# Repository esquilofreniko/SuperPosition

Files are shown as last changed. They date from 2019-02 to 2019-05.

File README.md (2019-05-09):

**SuperPosition – Rev 1**

**Bill of Materials:**

|Function / Name 		|# |Note 								|Part Number 		|
|---|--|---|---|
|MCU Teensy 3.5/3.6 	|1 |Cut USB power trace 				|DEV-14057 			|
|Display OLED SSD1306 	|1 |SSD1306 / SPI / 0.96’’ / 128x64 [1] | 					|
|Adafruit NeoTrellis 	|1 |4x4 RGB LED Button Matrix [2] 		|Mouser: 485-1616 	|
|Silicone 4x4 Keypad 	|1 |Silicone Elastomer Button Keypad [3]|Mouser: 485-1611 	|
|Rotary Encoder 		|2 |24 Pulse Mechanical Rotary Encoder 	|PEC11R-4220F -S0024|
|Tactile Switch 		|2 |9.4mm Black Button Tactile Switch 	|2-1825910-7 		|
|3.5mm Jacks 			|12 |“Thonkiconn” Mono Jacks from Thonk |PJ398SM 			|
|DAC MCP4922 			|2 |12-bit Digital to Analog Converter 	|MCP4922-E/P 		|
|Op-amp MCP6004 		|1 |Operational Amplifier 				|MCP6004-E/P 		|
|Op-amp TL04CN 			|2 |Operational Amplifier 				|TL074CN 			|
|Regulator L7805 		|1 |5V Voltage Regulator 				|L7805CP 			|
|Diode 1N5817 			|2 |Through Hole 						|1N5817 			|
|Resistor 100k SMD 0805 |24|0.1% 								| 					|
|Resistor 56k SMD 0805 	|4 |0.1% 								| 					|
|Resistor 1k SMD 0805 	|8 |1% 									| 					|
|Capacitor 10u SMD 0805 |2 |Ceramic Capacitor 					| 					|
|Capacitor 100n SMD 0805|6 |Ceramic Capacitor 					|					|

[1] https://www.amazon.co.uk/IZOKEE-Display-SSD1306-Raspberry-White-IIC/dp/B076PKKTRP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

[2] https://www.adafruit.com/product/3954

[3] https://www.adafruit.com/product/1611

**Build Guide (work in progress):**  

1. Solder the 2 10u 0805 SMT Capacitors in the front;

2. Solder the 6 100n 0805 SMT Capacitors in the back;

3. Solder all the 0805 SMT Resistors in the back;

4. Solder the 1N5817 Diodes in the back;

5. Solder the L7805 Voltage Regulator in the back;

6. Solder the Power Header in the back;

7. Solder the pin sockets for the teensy in the back;

8. Solder the ICs in the front (MCP6004, TL074CN, MCP4922);

9. Solder the buttons and encoders in the front;

10. Solder all of the jacks on the top;

11. Solder the Adafruit NeoTrellis PCB in the front;

12. Solder the OLED Display in the front;

13. Place the Panel on the front of the PCB;

14. Cut the USB power trace on the back of the teensy;

15. Place the teensy on the back;

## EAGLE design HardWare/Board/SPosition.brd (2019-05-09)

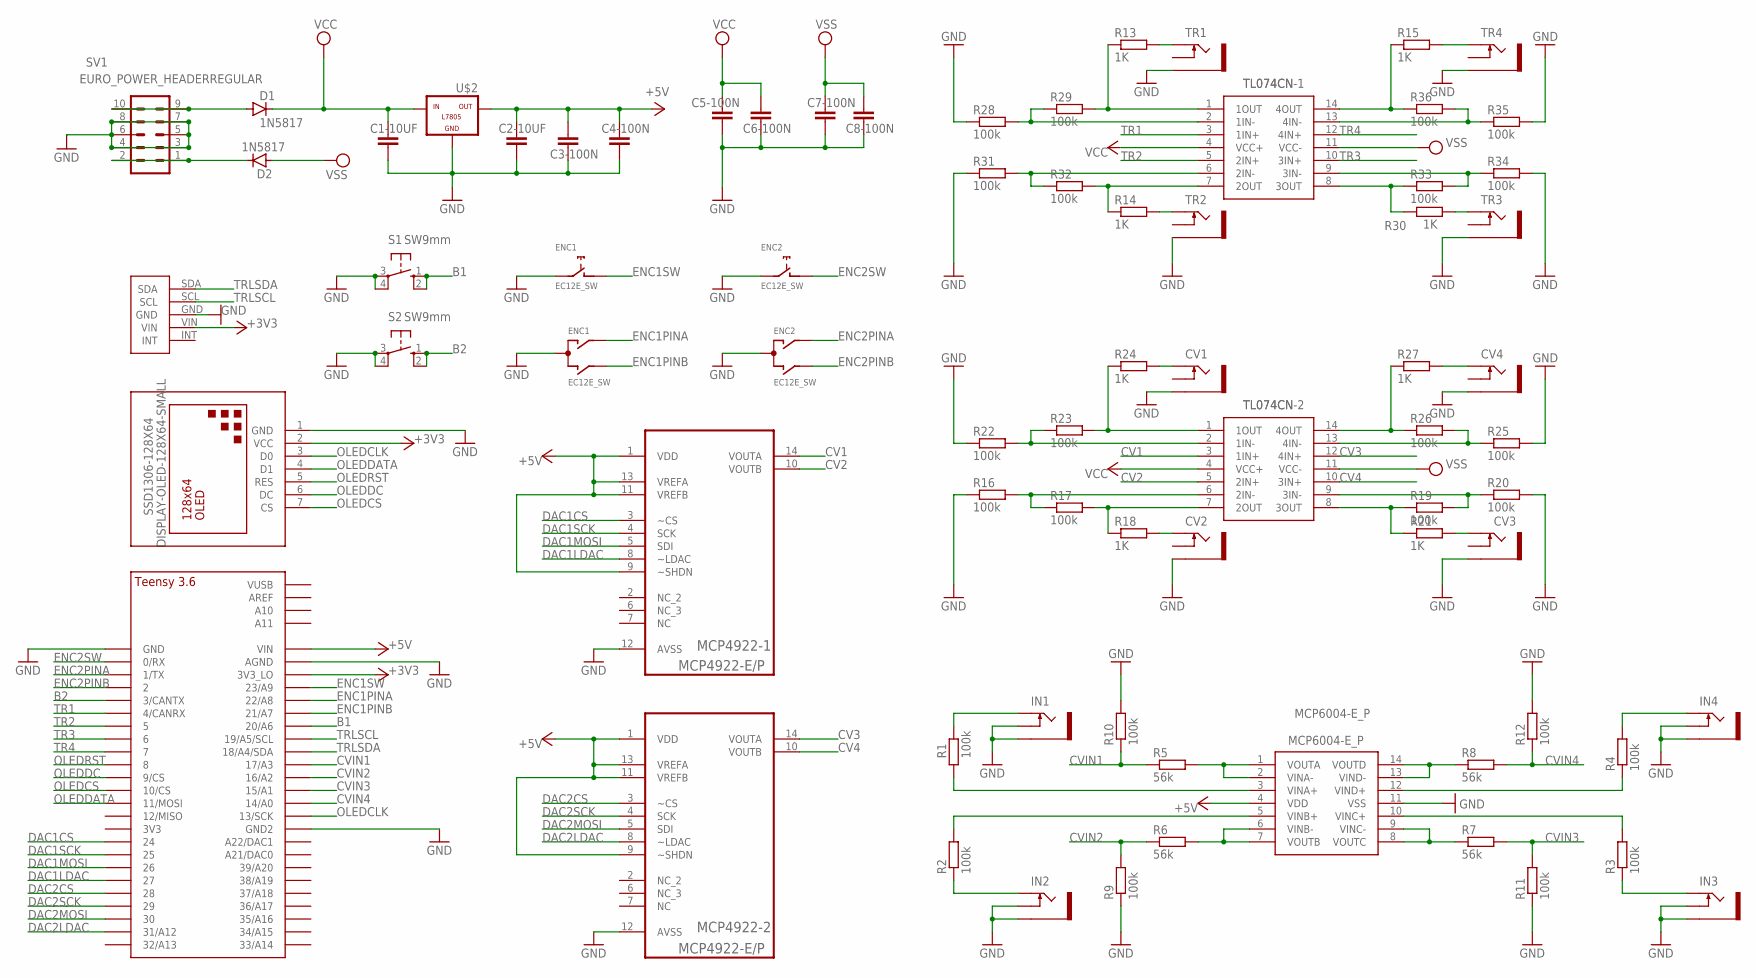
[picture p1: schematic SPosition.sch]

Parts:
C1-10UF, C2-10UF: 10uF; C0805
C3-100N, C4-100N, C5-100N, C6-100N, C7-100N, C8-100N: 100n; C0805
CV1, CV2, CV3, CV4: THONKICONNNEW; WQP-PJ301M-12_JACK
D1, D2: 1N5817; DO41-10
ENC1, ENC2: EC12E_SW; ALPS_EC12E_SW
IN1, IN2, IN3, IN4: THONKICONNNEW; WQP-PJ301M-12_JACK
MCP4922-1, MCP4922-2: MCP4922-E/P; DIP254P762X533-14
MCP6004-E_P: MCP6004-E_P; DIP781W56P254L1918H533Q14N
R1, R2, R3, R4, R9, R10, R11, R12, R16, R17, R19, R20, R22, R23, R25, R26, R28, R29, R31, R32, R33, R34, R35, R36: 100k; R0805
R5, R6, R7, R8: 56k; R0805
R13, R14, R15, R18, R21, R24, R27, R30: 1K; R0805
S1, S2: SW9mm; B3F-10XX
SSD1306-128X64: DISPLAY-OLED-128X64-SMALL
SV1: EURO_POWER_HEADERREGULAR; EURO_POWER_HEADER
TL074CN-1, TL074CN-2: TL074CN; DIP794W53P254L1930H508Q14N
TR1, TR2, TR3, TR4: THONKICONNNEW; WQP-PJ301M-12_JACK
U$1: TEENSY_3.5/3.6_BASIC
U$2: -L7805; L7805
U$4: SPREV5

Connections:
+3V3: SSD1306-128X64.2 (VCC), U$1.3V3_LO, U$4.VIN
+5V: C2-10UF.1, C3-100N.1, C4-100N.1, MCP4922-1.1 (VDD), MCP4922-1.9 (~SHDN), MCP4922-1.11 (VREFB), MCP4922-1.13 (VREFA), MCP4922-2.1 (VDD), MCP4922-2.9 (~SHDN), MCP4922-2.11 (VREFB), MCP4922-2.13 (VREFA), MCP6004-E_P.4 (VDD), U$1.VIN, U$2.OUT
B1: S1.1 (S), S1.2 (S1), U$1.20/A6
B2: S2.1 (S), S2.2 (S1), U$1.3/CANTX
CV1: MCP4922-1.14 (VOUTA), TL074CN-2.3 (1IN+)
CV2: MCP4922-1.10 (VOUTB), TL074CN-2.5 (2IN+)
CV3: MCP4922-2.14 (VOUTA), TL074CN-2.12 (4IN+)
CV4: MCP4922-2.10 (VOUTB), TL074CN-2.10 (3IN+)
CVIN1: R5.1, R10.1, U$1.17/A3
CVIN2: R6.1, R9.2, U$1.16/A2
CVIN3: R7.2, R11.2, U$1.15/A1
CVIN4: R8.2, R12.1, U$1.14/A0
DAC1CS: MCP4922-1.3 (~CS), U$1.24
DAC1LDAC: MCP4922-1.8 (~LDAC), U$1.27
DAC1MOSI: MCP4922-1.5 (SDI), U$1.26
DAC1SCK: MCP4922-1.4 (SCK), U$1.25
DAC2CS: MCP4922-2.3 (~CS), U$1.28
DAC2LDAC: MCP4922-2.8 (~LDAC), U$1.31/A12
DAC2MOSI: MCP4922-2.5 (SDI), U$1.30
DAC2SCK: MCP4922-2.4 (SCK), U$1.29
ENC1PINA: ENC1.A, U$1.22/A8
ENC1PINB: ENC1.B, U$1.21/A7
ENC1SW: ENC1.D (1), U$1.23/A9
ENC2PINA: ENC2.A, U$1.1/TX
ENC2PINB: ENC2.B, U$1.2
ENC2SW: ENC2.D (1), U$1.0/RX
GND: C1-10UF.2, C2-10UF.2, C3-100N.2, C4-100N.2, C5-100N.2, C6-100N.2, C7-100N.2, C8-100N.2, CV1.P$3_SLEEVE (SLEEVE), CV2.P$3_SLEEVE (SLEEVE), CV3.P$3_SLEEVE (SLEEVE), CV4.P$3_SLEEVE (SLEEVE), ENC1.C, ENC1.E (2), ENC2.C, ENC2.E (2), IN1.P$2_SWITCH (SWITCH), IN1.P$3_SLEEVE (SLEEVE), IN2.P$2_SWITCH (SWITCH), IN2.P$3_SLEEVE (SLEEVE), IN3.P$2_SWITCH (SWITCH), IN3.P$3_SLEEVE (SLEEVE), IN4.P$2_SWITCH (SWITCH), IN4.P$3_SLEEVE (SLEEVE), MCP4922-1.12 (AVSS), MCP4922-2.12 (AVSS), MCP6004-E_P.11 (VSS), R9.1, R10.2, R11.1, R12.2, R16.1, R20.2, R22.1, R25.2, R28.1, R31.1, R34.2, R35.2, S1.3, S1.4 (P1), S2.3, S2.4 (P1), SSD1306-128X64.1 (GND), SV1.3, SV1.4, SV1.5, SV1.6, SV1.7, SV1.8, TR1.P$3_SLEEVE (SLEEVE), TR2.P$3_SLEEVE (SLEEVE), TR3.P$3_SLEEVE (SLEEVE), TR4.P$3_SLEEVE (SLEEVE), U$1.AGND, U$1.GND, U$1.GND2, U$2.GND, U$4.GND
unnamed: D1.A, SV1.9, SV1.10
unnamed: R17.2, R18.1, TL074CN-2.7 (2OUT)
unnamed: IN1.P$1_TIP (TIP), R1.2
unnamed: MCP6004-E_P.6 (VINB-), MCP6004-E_P.7 (VOUTB), R6.2
unnamed: IN2.P$1_TIP (TIP), R2.1
unnamed: IN3.P$1_TIP (TIP), R3.1
unnamed: R14.1, R32.2, TL074CN-1.7 (2OUT)
unnamed: IN4.P$1_TIP (TIP), R4.2
unnamed: MCP6004-E_P.5 (VINB+), R2.2
unnamed: MCP6004-E_P.13 (VIND-), MCP6004-E_P.14 (VOUTD), R8.1
unnamed: MCP6004-E_P.8 (VOUTC), MCP6004-E_P.9 (VINC-), R7.1
unnamed: MCP6004-E_P.3 (VINA+), R1.1
unnamed: MCP6004-E_P.10 (VINC+), R3.2
unnamed: MCP6004-E_P.12 (VIND+), R4.1
unnamed: R16.2, R17.1, TL074CN-2.6 (2IN-)
unnamed: MCP6004-E_P.1 (VOUTA), MCP6004-E_P.2 (VINA-), R5.2
unnamed: CV2.P$1_TIP (TIP), R18.2
unnamed: CV3.P$1_TIP (TIP), R21.2
unnamed: R19.1, R21.1, TL074CN-2.8 (3OUT)
unnamed: R19.2, R20.1, TL074CN-2.9 (3IN-)
unnamed: R22.2, R23.1, TL074CN-2.2 (1IN-)
unnamed: R23.2, R24.1, TL074CN-2.1 (1OUT)
unnamed: CV1.P$1_TIP (TIP), R24.2
unnamed: R25.1, R26.2, TL074CN-2.13 (4IN-)
unnamed: R26.1, R27.1, TL074CN-2.14 (4OUT)
unnamed: CV4.P$1_TIP (TIP), R27.2
unnamed: D2.C, SV1.1, SV1.2
unnamed: R28.2, R29.1, TL074CN-1.2 (1IN-)
unnamed: R13.1, R29.2, TL074CN-1.1 (1OUT)
unnamed: R31.2, R32.1, TL074CN-1.6 (2IN-)
unnamed: R13.2, TR1.P$1_TIP (TIP)
unnamed: R14.2, TR2.P$1_TIP (TIP)
unnamed: R33.2, R34.1, TL074CN-1.9 (3IN-)
unnamed: R30.2, TR3.P$1_TIP (TIP)
unnamed: R30.1, R33.1, TL074CN-1.8 (3OUT)
unnamed: R35.1, R36.2, TL074CN-1.13 (4IN-)
unnamed: R15.1, R36.1, TL074CN-1.14 (4OUT)
unnamed: R15.2, TR4.P$1_TIP (TIP)
OLEDCLK: SSD1306-128X64.3 (D0), U$1.13/SCK
OLEDCS: SSD1306-128X64.7 (CS), U$1.10/CS
OLEDDATA: SSD1306-128X64.4 (D1), U$1.11/MOSI
OLEDDC: SSD1306-128X64.6 (DC), U$1.9/CS
OLEDRST: SSD1306-128X64.5 (RES), U$1.8
TR1: TL074CN-1.3 (1IN+), U$1.4/CANRX
TR2: TL074CN-1.5 (2IN+), U$1.5
TR3: TL074CN-1.10 (3IN+), U$1.6
TR4: TL074CN-1.12 (4IN+), U$1.7
TRLSCL: U$1.19/A5/SCL, U$4.SCL
TRLSDA: U$1.18/A4/SDA, U$4.SDA
VCC: C1-10UF.1, C5-100N.1, C6-100N.1, D1.C, TL074CN-1.4 (VCC+), TL074CN-2.4 (VCC+), U$2.IN
VSS: C7-100N.1, C8-100N.1, D2.A, TL074CN-1.11 (VCC-), TL074CN-2.11 (VCC-)

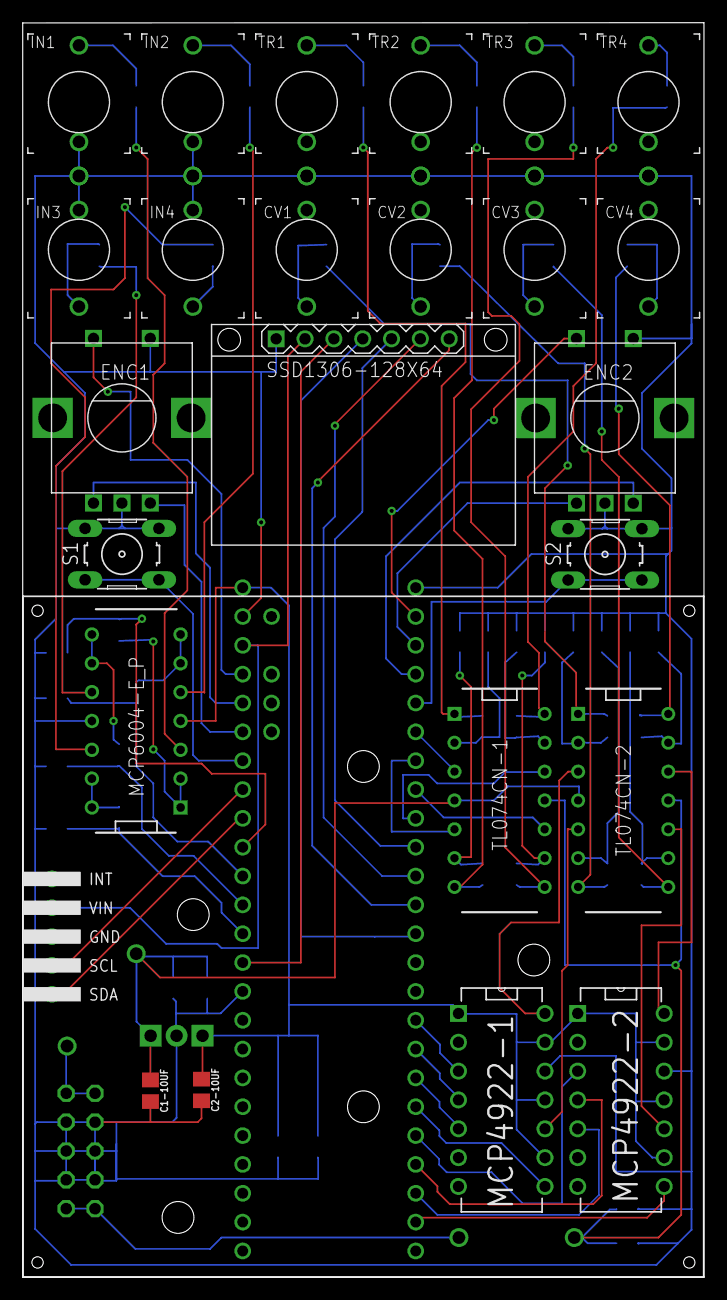
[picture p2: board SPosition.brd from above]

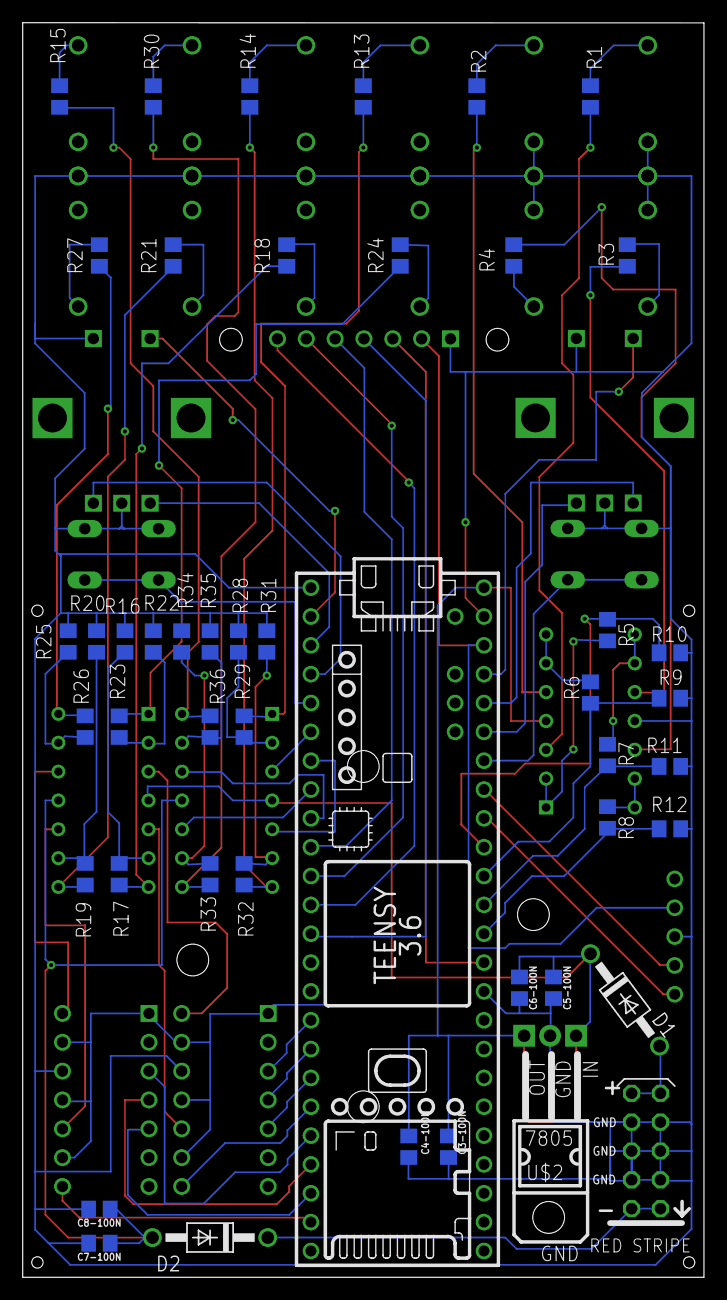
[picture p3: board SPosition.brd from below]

Board: 2 copper layers, 60.0 x 110.5 mm, 72 parts (47 on the bottom side), 78 nets.

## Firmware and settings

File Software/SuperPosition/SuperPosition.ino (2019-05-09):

#include "SP_hardware.h"
#include "SP_MODE.h"
int mode = 2;
int oldmode = mode;

void setup(){
  // loadPreset();
  hardware_init();
}

void loop(){
  hardware_read();
  if(mode == 0){mainMenu.run();}
  if(mode == 1){calibration.run();}
  if(mode == 2){gen.run();}
  if(oled.redraw == 1){oled.show();oled.redraw = 0;}
  if(millis() - oled.lastRedrawMS > 50){
    oled.clear();
    oled.redraw = 1;
    oled.lastRedrawMS = millis();
    // kp.show();
  }
  if(oldmode != mode){oled.clear();oled.redraw=1;oldmode=mode;}
}

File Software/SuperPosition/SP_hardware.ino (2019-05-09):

//Inputs
ADC::ADC(byte _pin1,byte _pin2,byte _pin3,byte _pin4):
  pin1(_pin1),
  pin2(_pin2),
  pin3(_pin3),
  pin4(_pin4)
{};

void ADC::init(){
  pin[0] = pin1;
  pin[1] = pin2;
  pin[2] = pin3;
  pin[3] = pin4;
  for(int i=0;i<4;i++){
    gate[4] = 0;
    _gate[4] = 0;
    pinMode(pin[i],INPUT);
  }
};

void ADC::read(){
  for(int i=3;i>-1;i--){
    trig[i] = 0;
    avg[i][avgCounter] = analogRead(pin[i]);
    gate[i] = digitalRead(pin[i]);
    if(gate[i] == 1 && _gate[i]==0){trig[i] = 1;}
    _gate[i] = gate[i];
  }
  avgCounter++;
  avgCounter %= avgMax;
  if(avgCounter == 0){    
    for(int i=3;i>-1;i--){
      in[i] = 0;
      for(int j=0;j<avgMax;j++){
        in[i] += avg[i][j];
      }
      in[i] = in[i] / avgMax;
    }
  }
};

//Digital Outputs
Gate::Gate(byte _pin1,byte _pin2,byte _pin3,byte _pin4):
  pin1(_pin1),
  pin2(_pin2),
  pin3(_pin3),
  pin4(_pin4)
{};

void Gate::init(){
  pin[0] = pin1;
  pin[1] = pin2;
  pin[2] = pin3;
  pin[3] = pin4;
  for(int i=0;i<4;i++){
    pinMode(pin[i],OUTPUT);
    digitalWrite(pin[i],0);
  };
}

void Gate::read(){
  for(int i=0;i<4;i++){
    if(trigger[i] == 1){
      if(val[i] == 1 && prev[i] == 0){
        trigStart = millis();
      }
      else if (val[i] == 1 && prev[i] == 1){
        if(millis() - trigStart > trigTime){
          digitalWrite(pin[i],0);
          val[i] = 0;
        }
      }
      prev[i] = val[i];
    }
  }
}

void Gate::write(byte channel, bool _val){
  digitalWrite(pin[channel],_val);
  val[channel] = _val;
}

//Analog Outputs
DAC::DAC(SP_MCP4922 _a1,SP_MCP4922 _a2,SP_MCP4922 _a3,SP_MCP4922 _a4):
a1(_a1),
a2(_a2),
a3(_a3),
a4(_a4)
{};

void DAC::init(){
  a1.setValue(0);
  a2.setValue(0);
  a3.setValue(0);
  a4.setValue(0);
};

void DAC::write(byte channel, float voltage){
  voltage = voltage * 0.99; //1k Output Resistor
  // if(voltage != 0){
  //   if(channel == 0){
  //     voltage += 0.012;
  //   }
  //   else if(channel == 1){
  //     voltage += 0.015;
  //   }
  //   else if(channel == 2){
  //     voltage += 0;
  //   }
  //   else if(channel == 3){
  //     voltage += 0.009;
  //   }
  // }
  int output = map(voltage,0,10,0,4095);
  if(channel == 0){
    a1.setValue(output);
  }
  else if(channel == 1){
    a2.setValue(output);
  }
  else if(channel == 2){
    a3.setValue(output);
  }
  else if(channel == 3){
    a4.setValue(output);
  }
};

//Buttons
Button::Button(byte _pin):
  pin(_pin)
{};

void Button::init() {
  pinMode(pin, INPUT_PULLUP);
  state = 1;
};

void Button::read() {
  clicked = 0;
  held_t = 0;
  bool prevHeld = held;
  int prevState = state;
  state = digitalRead(pin);
  if (prevState == 1 && state == 0){buttonDownMs = millis();}
  if (prevState == 0 && state == 1) {
    if (millis() - buttonDownMs < 25) {}
    else if (millis() - buttonDownMs < 500) {clicked = 1;}
  }
  if(state == 0){
    if(millis()-buttonDownMs >= 500){held = 1;}
    if(prevHeld == 0 && held == 1){held_t = 1;}
  }
  else if(state == 1){held = 0;}
};

//Encoders
RotaryEncoder::RotaryEncoder(byte _pinButton, Encoder _enc):
  pinButton(_pinButton),
  enc(_enc)
{}

void RotaryEncoder::init() {
  pinMode(pinButton,INPUT_PULLUP);
  state = 1;
}

void RotaryEncoder::read() {
  rotation = 0;
  if(pos != enc.read()){pos = enc.read();}
  if(pos > 3 || pos < -3){
    enc.write(0);
    post = 1;
  }
  if(post = 1){
    if(pos > 3){rotation = -1;}
    if(pos < -3){rotation = 1;}
    post = 0;
  }
  clicked = 0;
  held_t = 0;
  bool prevHeld = held;
  int prevState = state;
  state = digitalRead(pinButton);
  if (prevState == 1 && state == 0){buttonDownMs = millis();}
  if (prevState == 0 && state == 1) {
    if (millis() - buttonDownMs < 25) {}
    else if (millis() - buttonDownMs < 500) {clicked = 1;}
  }
  if(state == 0){
    if(millis()-buttonDownMs >= 500){held = 1;}
    if(prevHeld == 0 && held == 1){held_t = 1;}
  }
  else if(state == 1){held = 0;}
}

//KeyMatrix
TrellisCallback blink(keyEvent evt){
  if (evt.bit.EDGE == SEESAW_KEYPAD_EDGE_RISING) {
    kp.key[rotate1(evt.bit.NUM)] = 1;
    kp.pressed = 1;
  } else if (evt.bit.EDGE == SEESAW_KEYPAD_EDGE_FALLING) {
    kp.key[rotate1(evt.bit.NUM)] = 0;
    kp.released = 1;
  }
}

KeyMatrix::KeyMatrix(Adafruit_NeoTrellis _trellis):
  trellis(_trellis)
{}

void KeyMatrix::init(){
  if (!trellis.begin()) {while(1);}
  for(int i=0; i<16; i++){
    trellis.activateKey(i, SEESAW_KEYPAD_EDGE_RISING);
    trellis.activateKey(i, SEESAW_KEYPAD_EDGE_FALLING);
    trellis.registerCallback(i, blink);
  }
}

void KeyMatrix::read(){
  pressed = 0;
  released = 0;
  if(millis() - lastMillis >= 50){
    trellis.read();
    lastMillis = millis();
  }
}

void KeyMatrix::show(){
  trellis.pixels.show();
}
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

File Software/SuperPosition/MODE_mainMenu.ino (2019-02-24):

void MainMenu::run(){
  if(enc1.rotation != 0){
    selected += enc1.rotation;
    if(selected < 0){selected = 0;}
    if(selected > 1){selected = 1;}
    oled.redraw = 1;
  };
  if(oled.redraw == 1){
    oled.clear();
    for(int i=0;i<size;i++){
      if(i==selected){oled.drawText(0,i,1,menu[i].c_str());}
      else{oled.drawText(0,i,0,menu[i].c_str());}
    }
  }
  if(enc1.clicked == 1){
    mode = selected + 1;
    oled.clear();
  }
}

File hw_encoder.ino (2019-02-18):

#define ENCODER_DO_NOT_USE_INTERRUPTS
#include <Encoder.h>

class RotaryEncoder {
  const byte pinButton;
  bool state;
  unsigned int buttonDownMs;

  public:
  bool clicked;
  bool held;
  bool held_t;
  bool post;
  int pos;
  int rotation;
  Encoder enc;
  
  RotaryEncoder(byte _pinButton, Encoder _enc):
    pinButton(_pinButton),
    enc(_enc)
    {}
  
  void init() {
    pinMode(pinButton,INPUT_PULLUP);
    state = 1;
  }

  void read() {
    //Read Rotation
    rotation = 0;
    if(pos != enc.read()){pos = enc.read();}
    if(pos > 3 || pos < -3){
      enc.write(0);
      post = 1;
    }
    if(post = 1){
      if(pos > 3){rotation = -1;}
      if(pos < -3){rotation = 1;}
      Serial.println(enc.read());
      post = 0;
    }
    //Read Button
    clicked = 0;
    bool prevHeld = held;
    held = 0;
    held_t = 0;
    int prevState = state;
    state = digitalRead(pinButton);
    if (prevState == 1 && state == 0){buttonDownMs = millis();}
    else if (prevState == 0 && state == 1) {
      if (millis() - buttonDownMs < 50) {}
      else if (millis() - buttonDownMs < 1000) {clicked = 1;}
    }
    if(state == 0){
      if(millis()-buttonDownMs >= 1000){held = 1;}
    }
    if(prevHeld == 0 && held == 1){
      held_t = 1;
    }
  }
};

RotaryEncoder enc1(ENC1BUTTON,Encoder(ENC1PINA,ENC1PINB));
RotaryEncoder enc2(ENC2BUTTON,Encoder(ENC2PINA,ENC2PINB));

void encoder_init(){
  pinMode(ENC1PINA, INPUT_PULLUP);
  pinMode(ENC1PINB, INPUT_PULLUP);
  pinMode(ENC2PINA, INPUT_PULLUP);
  pinMode(ENC2PINB, INPUT_PULLUP);
  enc1.init();
  enc2.init();
}

void encoder_read(){
  enc1.read();
  enc2.read();
  if(enc1.held == 1){mode = 0;}
}

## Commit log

2019-01-23 started schematic
    [kaimat.kicad_pcb, kaimat.sch]
2019-02-06 added LEDS
    [_saved_kaimat.sch]
2019-02-06 optimized LEDS
2019-02-06 adding 2nd encoder
2019-02-06 added 2nd encoder
2019-02-08 added pannel
    [kaimat.sch]
2019-02-12 schematic finished
    [kaimat.sch]
2019-02-12 schematic improved
    [kaimat.sch]
2019-02-13 improved schematic
    [kaimat.kicad_pcb, kaimat.sch]
2019-02-13 changed teensy 3.2 to 3.6
    [kaimat.sch]
2019-02-15 improved schem
    [kaimat.sch]
2019-02-15 improved cod
    [kaimat.sch]
2019-02-17 pcb and eagle sch
    [kaimat.brd, kaimat.kicad_pcb, kaimat.sch]
2019-02-18 changed to 128x64 OLED, improved schematic and code (latency)
    [kaimat.brd, kaimat.sch]
2019-02-18 fixed issues with held encoder
    [hw_encoder.ino]
2019-02-20 improved circuit and pcb£
    [kaimat.brd, kaimat.sch]
2019-02-20 updated circuit and pcb
    [kaimat.brd, kaimat.sch]
2019-02-21 finished schematic
    [kaimat.brd, kaimat.sch]
2019-02-21 better pcb
    [kaimat.brd, kaimat.sch]
2019-02-23 finished pcb
    [kaimat.brd]
2019-02-24 better oled speed and better code
    [kaimat.brd]
2019-03-01 4 clocks
    [kaimat.brd]
2019-03-01 added length pararameter
    [copper_bottom.gbr, copper_top.gbr, drills.xln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]
2019-03-11 rev 2 pcb
    [SPosition.brd, SPosition.sch, kaimat.brd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]
2019-03-12 new pcb and schematic
    [SPosition.brd, SPosition.sch, kaimat.brd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]
2019-03-12 new pcb and pannel
    [SP_Pannel.brd, SP_Pannel.sch, SPosition.brd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]
2019-03-12 re-organizing directories
    [SP_Pannel.brd, SP_Pannel.sch, SPosition.brd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]
2019-03-12 pcb and pannel redesign
    [SP_hardware.h, SP_hardware.ino, SP_utils.ino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]
2019-03-12 board and schem revisions
    [SPosition.brd, SPosition.sch]
2019-03-12 schematic and pcb rev4
    [SPosition.brd, SPosition.sch]
2019-03-12 noise reduction capacitors
    [SPosition.brd]
2019-03-12 updated pcb and schematic
    [SPosition.brd]
2019-03-12 pcb optimization
    [SPosition.brd]
2019-03-13 pcb rev5
    [SPosition.brd, SPosition.sch]
2019-03-14 added gerber files
    [SP_Pannel.brd, SPosition.brd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]
2019-03-17 optimized code
    [SP_Pannel.brd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]
2019-03-27 pcb and pannel revision
    [SP_Pannel.brd, SPosition.brd, SPosition.sch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]
2019-04-05 prototype finalized
    [SP_Pannel.brd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]
2019-04-17 removed midi, debugging, fixed timing errors
    [MODE_gen.h, MODE_gen.ino]

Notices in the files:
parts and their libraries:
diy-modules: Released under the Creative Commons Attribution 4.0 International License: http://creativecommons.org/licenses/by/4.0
